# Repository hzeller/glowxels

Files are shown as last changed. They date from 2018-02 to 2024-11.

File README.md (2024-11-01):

Glowxels - Glow in the Dark Pixels
==================================

Driving 405nm LED line to make a pixelated glow-in-the-dark display.

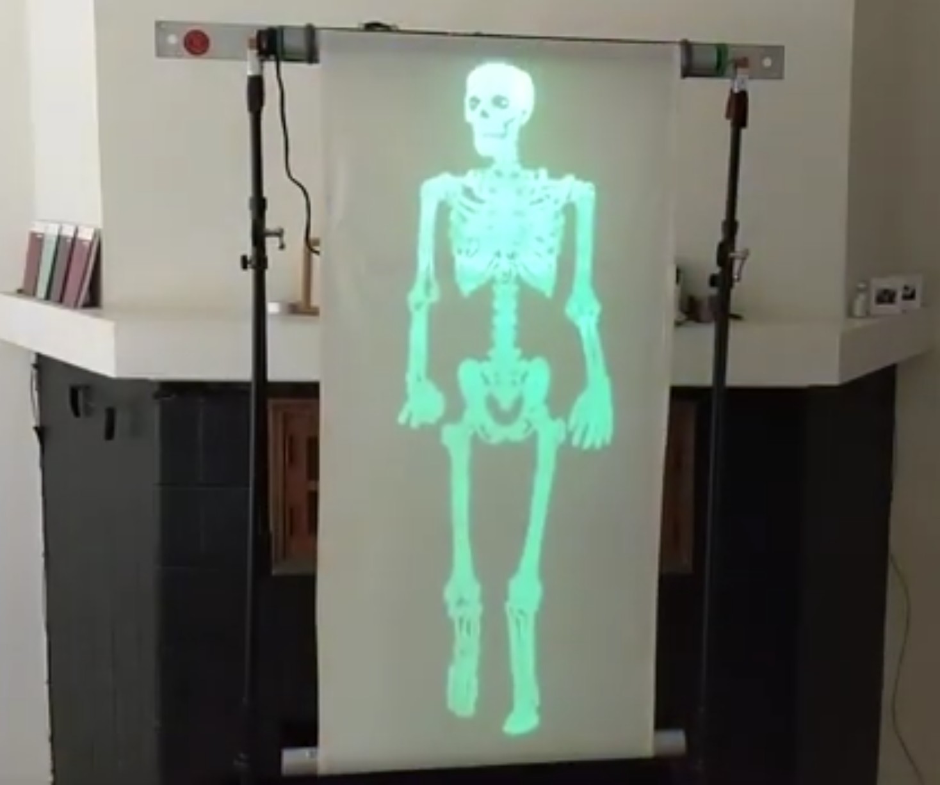
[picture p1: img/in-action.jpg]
Glow Screeen (https://youtu.be/4Vhdp7ZXU_8)


The pitch is relatively small with 1.5mm (667/meter). It is achived with two
rows with 3mm pitch of 3528 package mounted in a zig-zag pattern to have the
adjacent pixels without visible gap in X-direction.

The row distance in Y-direction is 3 pixels apart (4.5mm), so even and odd
pixels in a row will be sent 3 pixels spaced when sending.

Power for the LEDs is supplied with two rails on the back - in the installation
they are just mounted against two power rails.

The LEDs are driven by an [STP16CPC26]-chip - a neat 16 bit shift register with
constant current drivers. The serial data is just sent using the SPI bus on
the Raspberry Pi (with CS connected Latch), this is super-simple to wire.

Each board carries 64 LEDs and can be chained easily. The first glowxels screen
had 5 boards chained for 320 pixels on a 48cm wide screen.

A narrow version with 0.8mm pixel density is in the [feature-20240902-narrow](https://github.com/hzeller/glowxels/tree/feature-20240902-narrow) branch.

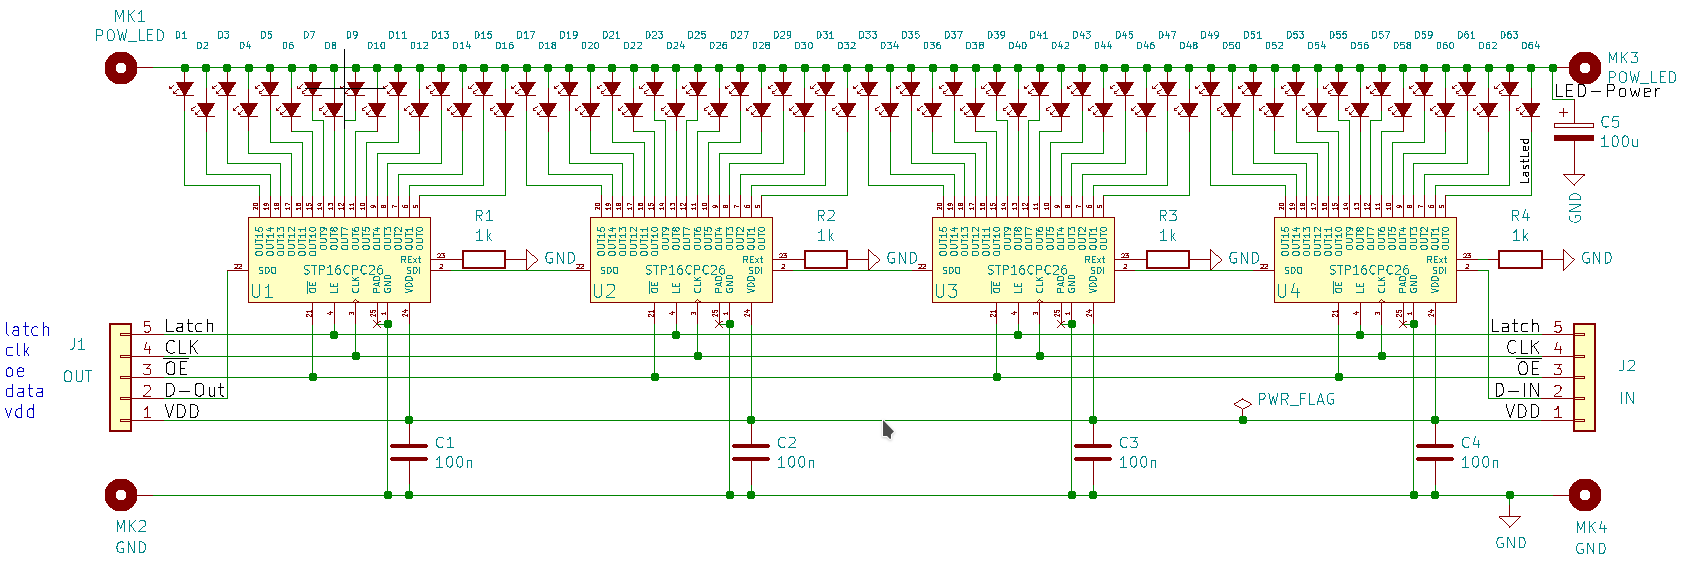
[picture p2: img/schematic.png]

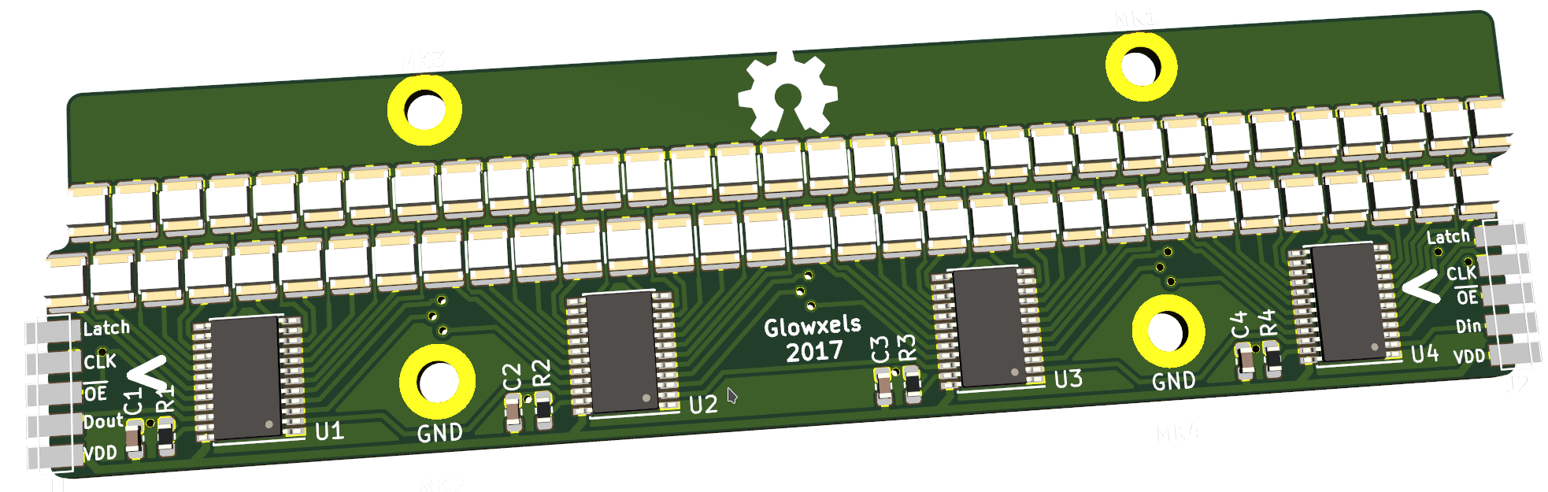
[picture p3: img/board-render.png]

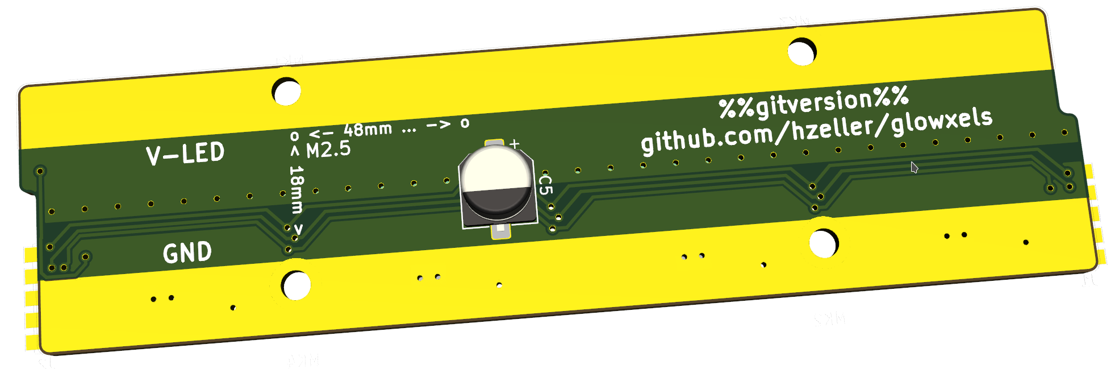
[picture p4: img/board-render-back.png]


[STP16CPC26]: http://www.st.com/resource/en/datasheet/stp16cpc26.pdf

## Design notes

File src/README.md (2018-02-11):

To compile: Needs wiringpi and libpng
```
sudo aptitude install wiringpi libpng-dev
```

Usage essentially:

```
usage: ./glow [options] <png-file>
Options:
        -d    : switch direction
        -i    : inverse image
```

Example:

```
  ./glow ~/someimage.png
```

Image needs to be 320 pixels wide.

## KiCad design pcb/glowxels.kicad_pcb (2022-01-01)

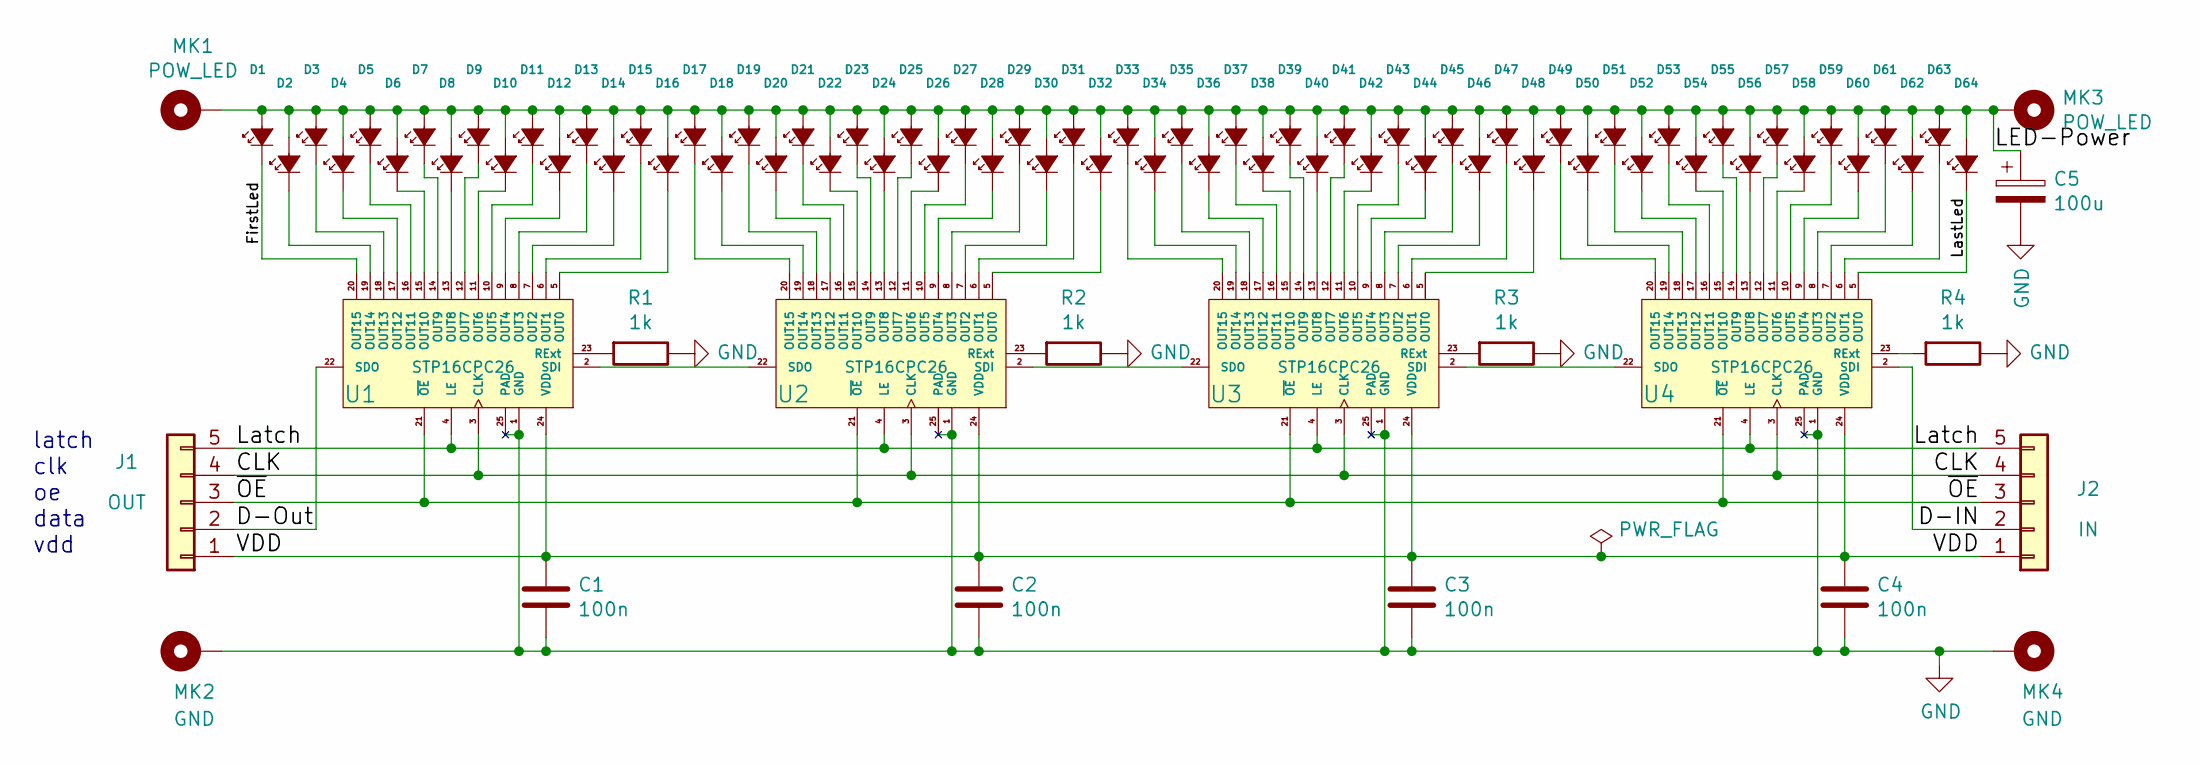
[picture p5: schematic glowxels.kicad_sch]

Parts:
C1, C2, C3, C4: 100n; C_0603_1608Metric
C5: 100u; CP_Elec_6.3x5.3
D1, D2, D3, D4, D5, D6, D7, D8, D9, D10, D11, D12, D13, D14, D15, D16, D17, D18, D19, D20, D21, D22, D23, D24, D25, D26, D27, D28, D29, D30, D31, D32, D33, D34, D35, D36, D37, D38, D39, D40, D41, D42, D43, D44, D45, D46, D47, D48, D49, D50, D51, D52, D53, D54, D55, D56, D57, D58, D59, D60, D61, D62, D63, D64: UV; LED_1210
J1: OUT; EdgeConnect
J2: IN; EdgeConnect
MK1, MK3: POW_LED; MountingHole_2.7mm_M2.5_DIN965_Pad
MK2, MK4: GND; MountingHole_2.7mm_M2.5_DIN965_Pad
R1, R2, R3, R4: 1k; R_0603_1608Metric
U1, U2, U3, U4: STP16CPC26; TSSOP-24EP_4.4x7.8mm_Pitch0.65mm

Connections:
/CLK: J1.4, J2.4, U1.3 (CLK), U2.3 (CLK), U3.3 (CLK), U4.3 (CLK)
/D-IN: J2.2, U4.2 (SDI)
/D-Out: J1.2, U1.22 (SDO)
/FirstLed: D1.1 (K), U1.20 (OUT15)
/LED-Power: C5.1, D1.2 (A), D2.2 (A), D3.2 (A), D4.2 (A), D5.2 (A), D6.2 (A), D7.2 (A), D8.2 (A), D9.2 (A), D10.2 (A), D11.2 (A), D12.2 (A), D13.2 (A), D14.2 (A), D15.2 (A), D16.2 (A), D17.2 (A), D18.2 (A), D19.2 (A), D20.2 (A), D21.2 (A), D22.2 (A), D23.2 (A), D24.2 (A), D25.2 (A), D26.2 (A), D27.2 (A), D28.2 (A), D29.2 (A), D30.2 (A), D31.2 (A), D32.2 (A), D33.2 (A), D34.2 (A), D35.2 (A), D36.2 (A), D37.2 (A), D38.2 (A), D39.2 (A), D40.2 (A), D41.2 (A), D42.2 (A), D43.2 (A), D44.2 (A), D45.2 (A), D46.2 (A), D47.2 (A), D48.2 (A), D49.2 (A), D50.2 (A), D51.2 (A), D52.2 (A), D53.2 (A), D54.2 (A), D55.2 (A), D56.2 (A), D57.2 (A), D58.2 (A), D59.2 (A), D60.2 (A), D61.2 (A), D62.2 (A), D63.2 (A), D64.2 (A), MK1.1, MK3.1
/LastLed: D64.1 (K), U4.5 (OUT0)
/Latch: J1.5, J2.5, U1.4 (LE), U2.4 (LE), U3.4 (LE), U4.4 (LE)
/VDD: C1.1, C2.1, C3.1, C4.1, J1.1, J2.1, U1.24 (VDD), U2.24 (VDD), U3.24 (VDD), U4.24 (VDD)
/~OE: J1.3, J2.3, U1.21 (~OE), U2.21 (~OE), U3.21 (~OE), U4.21 (~OE)
GND: C1.2, C2.2, C3.2, C4.2, C5.2, MK2.1, MK4.1, R1.1, R2.1, R3.1, R4.1, U1.1 (GND), U1.25 (PAD), U2.1 (GND), U2.25 (PAD), U3.1 (GND), U3.25 (PAD), U4.1 (GND), U4.25 (PAD)
unnamed: D2.1 (K), U1.19 (OUT14)
unnamed: D3.1 (K), U1.18 (OUT13)
unnamed: D4.1 (K), U1.17 (OUT12)
unnamed: D5.1 (K), U1.16 (OUT11)
unnamed: D6.1 (K), U1.15 (OUT10)
unnamed: D7.1 (K), U1.14 (OUT9)
unnamed: D8.1 (K), U1.13 (OUT8)
unnamed: D9.1 (K), U1.12 (OUT7)
unnamed: D10.1 (K), U1.11 (OUT6)
unnamed: D11.1 (K), U1.10 (OUT5)
unnamed: D12.1 (K), U1.9 (OUT4)
unnamed: D13.1 (K), U1.8 (OUT3)
unnamed: D14.1 (K), U1.7 (OUT2)
unnamed: D15.1 (K), U1.6 (OUT1)
unnamed: D16.1 (K), U1.5 (OUT0)
unnamed: D17.1 (K), U2.20 (OUT15)
unnamed: D18.1 (K), U2.19 (OUT14)
unnamed: D19.1 (K), U2.18 (OUT13)
unnamed: D20.1 (K), U2.17 (OUT12)
unnamed: D21.1 (K), U2.16 (OUT11)
unnamed: D22.1 (K), U2.15 (OUT10)
unnamed: D23.1 (K), U2.14 (OUT9)
unnamed: D24.1 (K), U2.13 (OUT8)
unnamed: D25.1 (K), U2.12 (OUT7)
unnamed: D26.1 (K), U2.11 (OUT6)
unnamed: D27.1 (K), U2.10 (OUT5)
unnamed: D28.1 (K), U2.9 (OUT4)
unnamed: D29.1 (K), U2.8 (OUT3)
unnamed: D30.1 (K), U2.7 (OUT2)
unnamed: D31.1 (K), U2.6 (OUT1)
unnamed: D32.1 (K), U2.5 (OUT0)
unnamed: D33.1 (K), U3.20 (OUT15)
unnamed: D34.1 (K), U3.19 (OUT14)
unnamed: D35.1 (K), U3.18 (OUT13)
unnamed: D36.1 (K), U3.17 (OUT12)
unnamed: D37.1 (K), U3.16 (OUT11)
unnamed: D38.1 (K), U3.15 (OUT10)
unnamed: D39.1 (K), U3.14 (OUT9)
unnamed: D40.1 (K), U3.13 (OUT8)
unnamed: D41.1 (K), U3.12 (OUT7)
unnamed: D42.1 (K), U3.11 (OUT6)
unnamed: D43.1 (K), U3.10 (OUT5)
unnamed: D44.1 (K), U3.9 (OUT4)
unnamed: D45.1 (K), U3.8 (OUT3)
unnamed: D46.1 (K), U3.7 (OUT2)
unnamed: D47.1 (K), U3.6 (OUT1)
unnamed: D48.1 (K), U3.5 (OUT0)
unnamed: D49.1 (K), U4.20 (OUT15)
unnamed: D50.1 (K), U4.19 (OUT14)
unnamed: D51.1 (K), U4.18 (OUT13)
unnamed: D52.1 (K), U4.17 (OUT12)
unnamed: D53.1 (K), U4.16 (OUT11)
unnamed: D54.1 (K), U4.15 (OUT10)
unnamed: D55.1 (K), U4.14 (OUT9)
unnamed: D56.1 (K), U4.13 (OUT8)
unnamed: D57.1 (K), U4.12 (OUT7)
unnamed: D58.1 (K), U4.11 (OUT6)
unnamed: D59.1 (K), U4.10 (OUT5)
unnamed: D60.1 (K), U4.9 (OUT4)
unnamed: D61.1 (K), U4.8 (OUT3)
unnamed: D62.1 (K), U4.7 (OUT2)
unnamed: D63.1 (K), U4.6 (OUT1)
unnamed: R1.2, U1.23 (RExt)
unnamed: R2.2, U2.23 (RExt)
unnamed: R3.2, U3.23 (RExt)
unnamed: R4.2, U4.23 (RExt)
unnamed: U1.2 (SDI), U2.22 (SDO)
unnamed: U2.2 (SDI), U3.22 (SDO)
unnamed: U3.2 (SDI), U4.22 (SDO)

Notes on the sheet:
latch clk oe data vdd

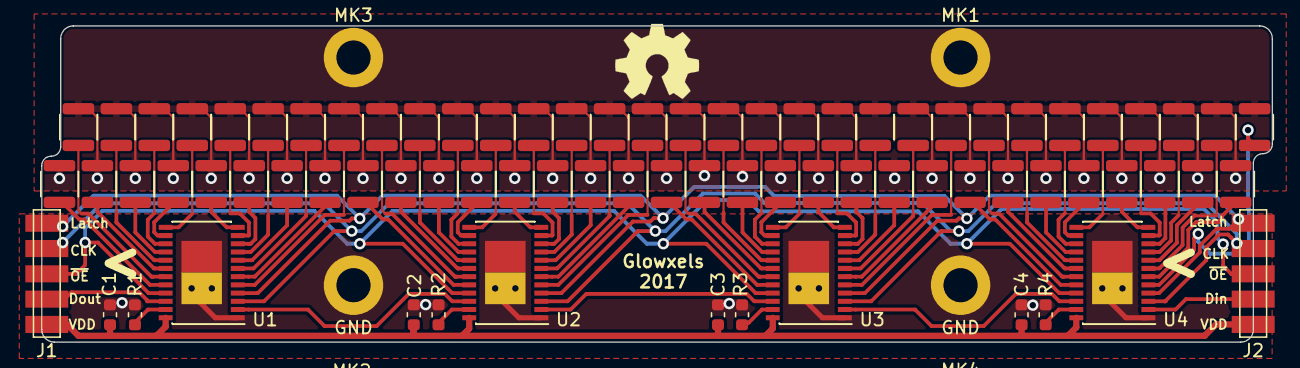
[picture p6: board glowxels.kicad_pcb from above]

Board: 2 copper layers, 97.3 x 25.0 mm, 83 parts (1 on the bottom side), 79 nets.

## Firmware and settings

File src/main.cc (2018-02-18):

// -*- mode: c++; c-basic-offset: 4; indent-tabs-mode: nil; -*-
// (c) 2017 Henner Zeller <h.zeller@acm.org>
//
// This file is part of Gloxels. http://glowxels.net/
//
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
#include <getopt.h>

#include <memory>

#include "image-processing.h"
#include "glowxel-screen.h"

int usage(const char *progname) {
    fprintf(stderr, "usage: %s [options] <png-file> [<png-file>...]\n",
            progname);
    fprintf(stderr, "Options:\n"
            "\t-i    : inverse image\n"
            "\t-r    : Retract to last write position before showing image.\n"
            "\t-F    : fast (slightly lower brightness + quality)\n"
            "\t-b<%%> : Brightness percent. Default 70.\n"
            );
    return 1;
}

int main(int argc, char *argv[]) {
    bool dir = false;
    bool inverse = true;
    bool retract = false;
    bool fast = false;
    float brightness = 0.7;

    int opt;
    while ((opt = getopt(argc, argv, "dirb:F")) != -1) {
        switch (opt) {
        case 'd': dir = !dir; break;  // In case the motor is wired backwards.
        case 'i': inverse = !inverse; break;
        case 'r': retract = true; break;
        case 'b': brightness = atof(optarg) / 100.0; break;
        case 'F': fast = true; break;
        default:
            return usage(argv[0]);
        }
    }

    if (brightness < 0 || brightness > 1.0) {
        fprintf(stderr, "Brightness needs to be betwen 1..100%%\n");
        return usage(argv[0]);
    }

    if (optind >= argc)
        return usage(argv[0]);


    std::unique_ptr<GlowxelScreen> screen(GlowxelScreen::CreateInstance(dir));
    if (!screen) {
        fprintf(stderr, "Could not initialize hardware\n");
        return 1;
    }

    screen->SetFast(fast);
    screen->SetBrightness(brightness);

    if (retract) screen->Retract();

    for (int imgarg = optind; imgarg < argc; ++imgarg) {
        const char *filename = argv[imgarg];
        BitmapImage *img = LoadPNGImage(filename, inverse);
        if (!img) {
            fprintf(stderr, "Couldn't open %s\n", filename);
            continue;
        }
        fprintf(stderr, "Showing %s %dx%d\n",
                filename, img->width(), img->height());
        screen->ShowImage(*img);
        delete img;
    }

    screen->Eject();
}

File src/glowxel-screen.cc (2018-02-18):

// -*- mode: c++; c-basic-offset: 4; indent-tabs-mode: nil; -*-
// (c) 2018 Henner Zeller <h.zeller@acm.org>
//
// This file is part of Gloxels. http://glowxels.net/
//
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
#include "glowxel-screen.h"

#include <unistd.h>
#include <wiringPi.h>
#include <wiringPiSPI.h>

/*
 * Here are some hardcoded constants matching the
 * one instance in existence :)
 */

// Our screen has 320 pixels accross.
static constexpr int kRowLengthBytes = 320 / 8;

// Stepmotor steps with each pixel. This is specific to the mounting
// set-up, diameter of roller etc.
static constexpr int kStepsPerPixel = 36;
static constexpr int kCanvasEjectSteps = 50 * kStepsPerPixel;

// Steps we use to accelerate and decelerate. We're not doing any kind of
// trapezoidal acceleration, just jump from zero to half-speed
// for kAccelerateSteps before we do full speed. Good enough.
static constexpr int kAccelerateSteps = 20 * kStepsPerPixel;

static constexpr int kRegularStepDelay = 200;
static constexpr int kFastStepDelay = 100;

/* the wiringPi libray has some WTF random assignments to what it calls
 * Pins, but they have nothing to do with the GPIO pins.
 * http://wiringpi.com/pins/special-pin-functions/
 *
 * Bring back some sanity.
 */
enum GPIO_NAMES {
    GPIO_18 = 1,  // header 12
    GPIO_22 = 3,  // header 15
    GPIO_23 = 4,  // header 16
    GPIO_24 = 5   // header 18
};

// Data on SPI: MOSI:header19, SCLK:header23, CE0=Latch:header24

// Our logical names
#define OUTPUT_ENABLE GPIO_18
#define MOTOR_ENABLE  GPIO_22
#define MOTOR_STEP    GPIO_24
#define MOTOR_DIR     GPIO_23

GlowxelScreen *GlowxelScreen::CreateInstance(bool reverse_stepper_direction) {
    if (wiringPiSetup() < 0) {
        perror("Could not initialize wiringPi");
        return nullptr;
    }
    if (wiringPiSPISetup(0, 500000) < 0) {
        perror("Could not open SPI");
        return nullptr;
    }

    return new GlowxelScreen(reverse_stepper_direction);
}

GlowxelScreen::GlowxelScreen(bool reverse_stepper_direction)
    : stepper_direction_wiring_(reverse_stepper_direction),
      brightness_(0.7), step_delay_(kRegularStepDelay),
      motor_is_on_(false), motor_direction_(false) {
    pinMode(OUTPUT_ENABLE, OUTPUT);     // Maybe later PWM ?
    pinMode(MOTOR_ENABLE, OUTPUT);
    pinMode(MOTOR_STEP, OUTPUT);
    pinMode(MOTOR_DIR, OUTPUT);
}

GlowxelScreen::~GlowxelScreen() {
    digitalWrite(OUTPUT_ENABLE, HIGH);  // Should be turned off, but extra sure.
    digitalWrite(MOTOR_ENABLE, HIGH);   // Set motor to coasting again.
}

void GlowxelScreen::SetBrightness(float b) {
    if (b >= 0.0 && b <= 1.0) brightness_ = b;
}

void GlowxelScreen::SetFast(bool fast) {
    step_delay_ = fast ? kFastStepDelay : kRegularStepDelay;
}

static void motorSteps(int steps, int step_delay) {
    for (int i = 0; i < steps; ++i) {
        // For our application, usleep() is good enough; no realtimeness needed
        usleep(step_delay);
        digitalWrite(MOTOR_STEP, LOW);
        usleep(step_delay);
        digitalWrite(MOTOR_STEP, HIGH);
    }
}

bool GlowxelScreen::SetMotorState(bool on, bool dir) {
    dir ^= stepper_direction_wiring_;
    if (motor_is_on_ == on && dir == motor_direction_)
        return false;
    digitalWrite(MOTOR_DIR, dir ? LOW : HIGH);
    motor_direction_ = dir;
    digitalWrite(MOTOR_ENABLE, on ? LOW : HIGH);
    motor_is_on_ = on;
    return true;
}

// Get row if it is within range or return fallback buffer if not.
static const uint8_t *RowOrFallback(const BitmapImage &img, int row,
                                    const uint8_t *fallback) {
    if (row < 0 || row >= img.height()) return fallback;
    return img.GetRow(row);
}

void GlowxelScreen::ShowImage(const BitmapImage &img) {
    if (SetMotorState(true, true)) {
        // Need to do some acceleration first.
        motorSteps(kAccelerateSteps, 2*step_delay_);
    }

    const int image_width_bytes = std::min(img.width() / 8, kRowLengthBytes);
    const int y_pixel_offset = 3;  // LEDs are mounted zigzag offset with 3.
    unsigned char *const buffer = new unsigned char[kRowLengthBytes];
    const int start_byte = kRowLengthBytes - image_width_bytes;
    const int light_steps = std::max(0.0f, brightness_ * kStepsPerPixel);
    const int dark_steps = kStepsPerPixel - light_steps;

    for (int r = img.height() - 1; r >= -y_pixel_offset; --r) {
        memset(buffer, 0x00, kRowLengthBytes);
        // If outside pixel range, we just alias with our empty buffer
        const uint8_t *first  = RowOrFallback(img, r, buffer);
        const uint8_t *second = RowOrFallback(img, r + y_pixel_offset, buffer);
        for (int i = 0; i < image_width_bytes; ++i) {
            // Alternative bits from alternative rows to match zig-zag LED mount
            buffer[start_byte+i] = (*first++ & 0x55) | (*second++ & 0xaa);
        }
        wiringPiSPIDataRW(0, buffer, kRowLengthBytes);
        digitalWrite(OUTPUT_ENABLE, LOW);
        motorSteps(light_steps, step_delay_);
        digitalWrite(OUTPUT_ENABLE, HIGH);
        motorSteps(dark_steps, step_delay_);
    }
    delete [] buffer;
}

void GlowxelScreen::Retract(int extra_pixels) {
    SetMotorState(true, false);
    motorSteps(kAccelerateSteps, 2*step_delay_);
    motorSteps(kCanvasEjectSteps - kAccelerateSteps, step_delay_);
    // decelerate, and prepare for the acceleration
    motorSteps(kAccelerateSteps + extra_pixels*kStepsPerPixel, 2*step_delay_);
}

void GlowxelScreen::Eject(int extra_pixels) {
    motorSteps(kCanvasEjectSteps - kAccelerateSteps, step_delay_);
    motorSteps(kAccelerateSteps + extra_pixels*kStepsPerPixel, 2*step_delay_);
    SetMotorState(false, true);
}

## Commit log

2017-12-22 Initial simple board.
    64 LEDs with a distance of 1.5mm (two offset rows 4.5mm apart,
    with 3mm distance between LEDs in each row).
    [glowxels.kicad_pcb, glowxels.sch]
2017-12-22 Use git version number in back silkscreen.
2017-12-22 Silkscreen optimization: mark power rails on back.
    [glowxels.kicad_pcb]
2018-01-30 Add OSHW silkscreen.
    [glowxels.kicad_pcb]
2018-01-30 Chaining connector: use space and increase pitch 1.27mm -> 2.0mm
    [glowxels.kicad_pcb, glowxels.sch]
2018-02-11 rename glowxels/ -> pcb/. Smallish tweak in PCB.
    [glowxels.kicad_pcb, glowxels.sch]
2018-02-18 Move Glowxel emitting to separate class.
    o Create class GlowxelScreen where the screen control
    is encapcsulated.
    o since the current LED array is mounted backwards in
    the prototype, reverse all the bits.
    [glowxel-screen.cc, main.cc]
2018-02-18 Only accelerate on first image. Simplify empty row code.
    o For multiple images, only the first image requires acceleration
    of the canvas. Make it so.
    o instead of a clunky nullptr comparison, just use the zeroed
    buffer for the empty data source for the y pixels that go
    beyond the range due to the zig-zag LED mounting.
2019-05-06 Update to work with schematic and footprint library of 5.1
    [glowxels.kicad_pcb, glowxels.sch]
2019-05-06 Smaller schematic render (forces less antialiasing in smaller display)
2019-05-06 Add inner edge fillet; connect LED power plane with thermal reliefs.
    [glowxels.kicad_pcb, glowxels.sch]
2022-01-01 Adapt to Kicad 6
    [glowxels.kicad_pcb, glowxels.kicad_sch, glowxels.sch]
2024-09-02 Adapt to current kicad python lib.

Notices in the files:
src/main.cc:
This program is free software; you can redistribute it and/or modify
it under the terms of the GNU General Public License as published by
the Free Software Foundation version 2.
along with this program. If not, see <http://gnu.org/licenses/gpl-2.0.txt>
